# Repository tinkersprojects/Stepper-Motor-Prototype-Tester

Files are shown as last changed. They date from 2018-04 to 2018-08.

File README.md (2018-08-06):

# Stepper-Motor-Prototype-Tester
[https://tinkersprojects.com/](https://tinkersprojects.com/)

This controller is made as a prototype tool to test mechanics from a stepper motor. On the controller, there is a button which is used to change the state of the motor. The controller can have 2 states set, one while the button is pressed ad one while the button is not pressed. The controller can be set using a serial user interface. There are 4 different states that can be set; stop, move to a position, move amount and continuously moving. Stop is stop to stop the motor. Move to a position is to move to a set position. Move amount is to move a set amount no matter what the other set state is. Continuously moving make the motor continuously move at a set speed in a direction.

2 different or the same state can be set, for example; state 1 (button = 0) is continuously moving and state 2 (button = 1) is Move to a position. This will make the motor continuously run but when the button is pressed, the motor will go to the set position. This means that the motor will return to the same spot even tho it has moved away at a random distance.
Another example would be setting the same state but with different speed setting or position settings.
To access the menu, plug the controller into the USB and the menu will appear in the serial console. This menu allows you to set how the controller reacts to the button press.
Welcome v1.0 Stepper motor controller

```
Commads:
    P – Program (ON Type, ON Distance, ON Speed, OFF Type, OFF Distance, OFF Speed)
    A – Move amount (Distance)
    T – Move To positon (Distance)
    S – Set setting (m1, m2, m3)
    D – Display details
    H – Help
Serial.println();
Type:
    0 – Stop
    1 – Move to position
    2 – Move amount
    3 – Continuously moving
```

The Arduino program and PCB is available from https://github.com/tinkersprojects/Stepper-Motor-Prototype-Tester
The PCB is available from https://tinkersprojects.com/product/stepper-motor-prototype-tester/

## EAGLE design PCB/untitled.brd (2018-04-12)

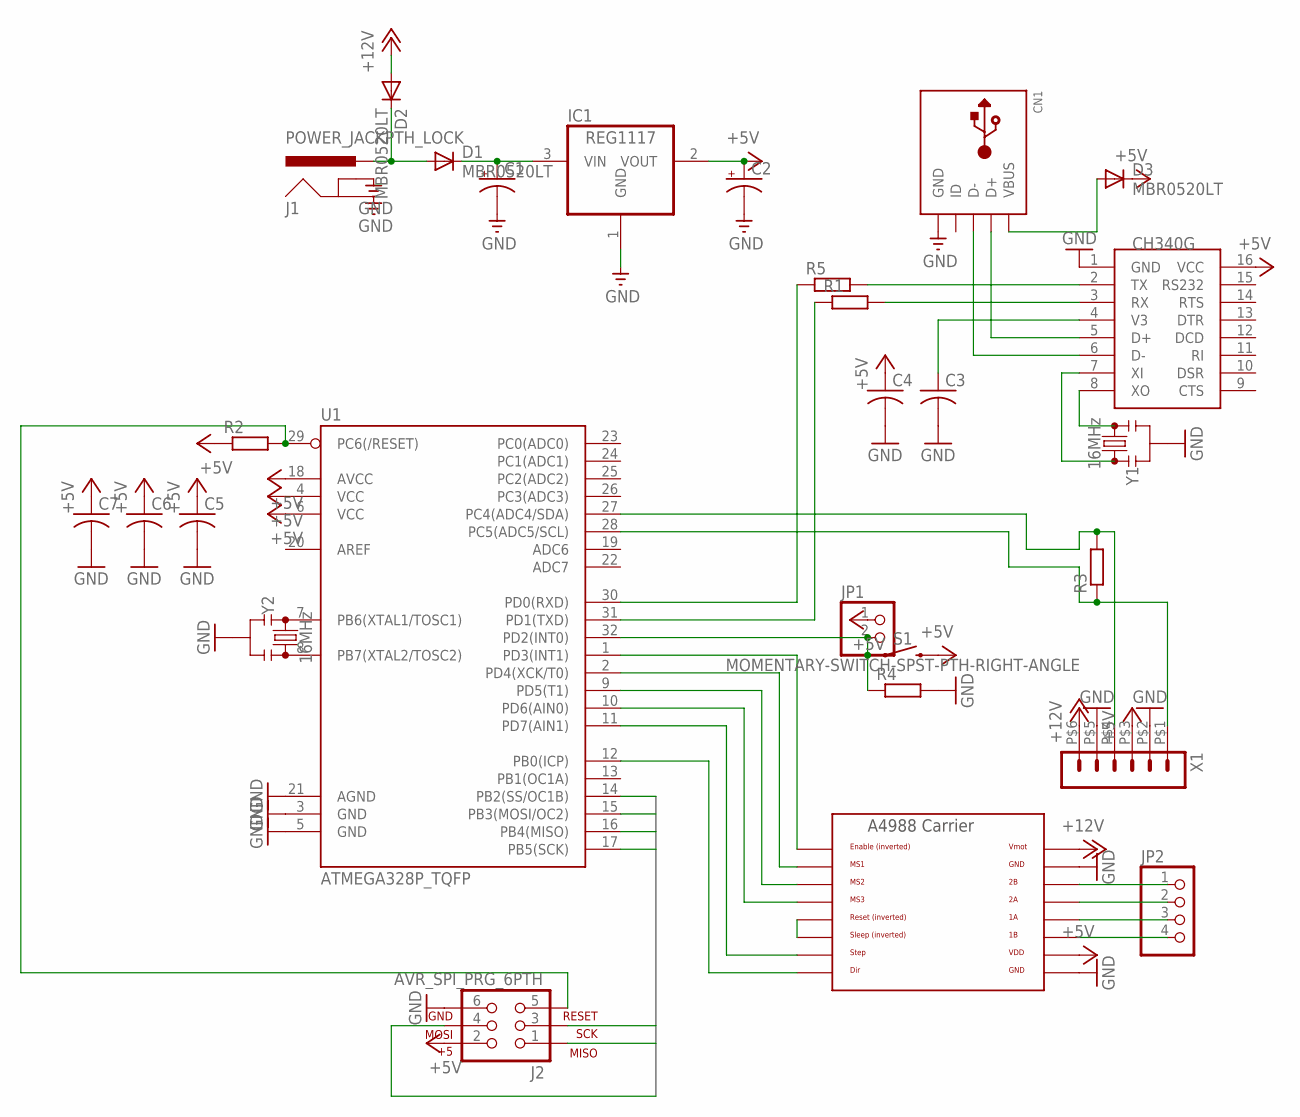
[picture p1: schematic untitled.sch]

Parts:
C1, C2: CPOL-US153CLV-0405; 153CLV-0405
C3, C4, C5, C6, C7: C-USC1210; C1210
CN1: USBMINIB; USB-MINIB
D1, D2, D3: MBR0520LT; SOD123
IC1: REG1117; SOT223
J1: POWER_JACKPTH_LOCK; POWER_JACK_PTH_LOCK
J2: AVR_SPI_PRG_6PTH; 2X3
JP1: PINHD-1X2; 1X02
JP2: PINHD-1X4; 1X04
R1, R2, R3, R4, R5: R-EU_MELF0207W; MINI_MELF-0207W
S1: MOMENTARY-SWITCH-SPST-PTH-RIGHT-ANGLE; TACTILE_SWITCH_PTH_RIGHT_ANGLE
U1: ATMEGA328P_TQFP; TQFP32-08
U$1: CH340G; SOIC16
U$2: A4988BREAKOUT
X1: HEADER_POS6_43045-0600; 43045-0600
Y1, Y2: 16MHz; RESONATOR-SMD-3.2X1.3

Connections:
+5V: C2.+, C4.1, C5.1, C6.1, C7.1, D3.C, IC1.2 (VOUT), J2.2, JP1.1, R2.1, S1.2, U1.4 (VCC), U1.6 (VCC), U1.18 (AVCC), U$1.16 (VCC), U$2.VDD, X1.P$3 (3)
+12V: D2.A, U$2.VMOT, X1.P$6 (6)
CAN_CS: U1.14 (PB2(SS/OC1B))
GND: C1.-, C2.-, C3.2, C4.2, C5.2, C6.2, C7.2, CN1.GND, IC1.1 (GND), J1.GND, J1.GNDBREAK, J2.6, R4.2, U1.3 (GND), U1.5 (GND), U1.21 (AGND), U$1.1 (GND), U$2.GND, U$2.GND@0 (GND), X1.P$2 (2), X1.P$5 (5), Y1.2, Y2.2
MISO: J2.1, U1.16 (PB4(MISO))
MOSI: J2.4, U1.15 (PB3(MOSI/OC2))
unnamed: D1.A, D2.C, J1.PWR
unnamed: R1.2, U$1.3 (RX)
unnamed: U1.1 (PD3(INT1)), U$2.EN
unnamed: U1.2 (PD4(XCK/T0)), U$2.MS1
unnamed: U1.8 (PB7(XTAL2/TOSC2)), Y2.3
unnamed: U1.7 (PB6(XTAL1/TOSC1)), Y2.1
unnamed: J2.5, R2.2, U1.29 (PC6(/RESET))
unnamed: R3.2, U1.27 (PC4(ADC4/SDA)), X1.P$4 (4)
unnamed: U1.9 (PD5(T1)), U$2.MS2
unnamed: U1.10 (PD6(AIN0)), U$2.MS3
unnamed: R3.1, U1.28 (PC5(ADC5/SCL)), X1.P$1 (1)
unnamed: C1.+, D1.C, IC1.3 (VIN)
unnamed: JP1.2, R4.1, S1.1, U1.32 (PD2(INT0))
unnamed: U1.11 (PD7(AIN1)), U$2.STEP
unnamed: U1.12 (PB0(ICP)), U$2.DIR
unnamed: U$2.RST, U$2.SLP (SLEEP)
unnamed: JP2.1, U$2.2B
unnamed: JP2.2, U$2.2A
unnamed: JP2.3, U$2.1A
unnamed: JP2.4, U$2.1B
unnamed: U$1.8 (XO), Y1.3
unnamed: U$1.7 (XI), Y1.1
unnamed: R5.1, U1.30 (PD0(RXD))
unnamed: R1.1, U1.31 (PD1(TXD))
unnamed: R5.2, U$1.2 (TX)
unnamed: CN1.D+, U$1.5 (D+)
unnamed: CN1.D-, U$1.6 (D-)
unnamed: CN1.VBUS, D3.A
unnamed: C3.1, U$1.4 (V3)
SCK: J2.3, U1.17 (PB5(SCK))

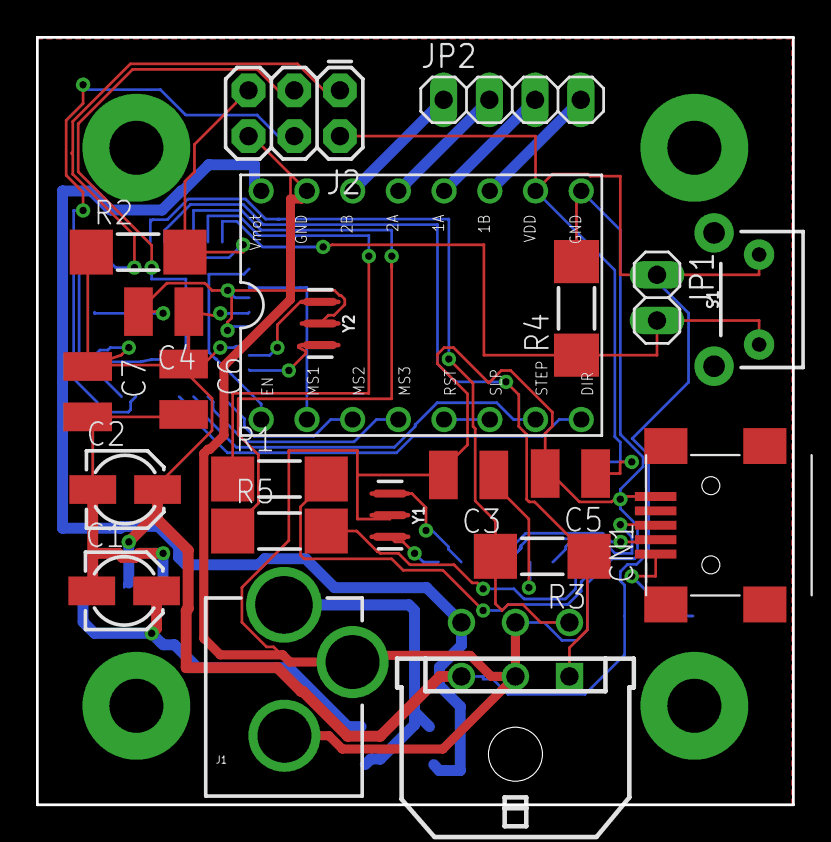
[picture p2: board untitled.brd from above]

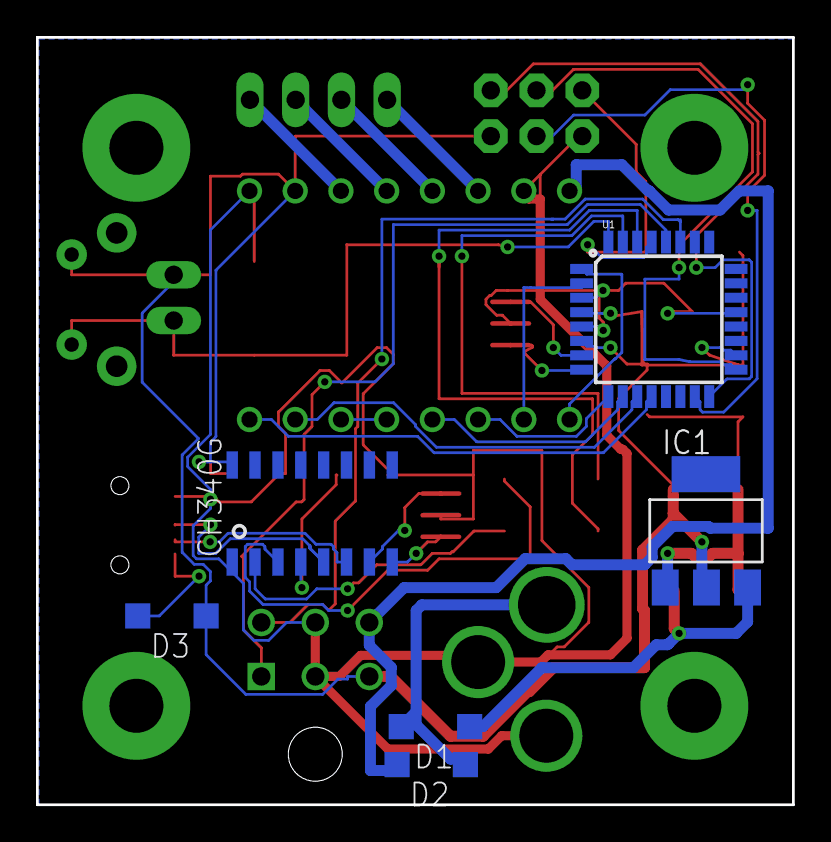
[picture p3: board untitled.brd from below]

Board: 2 copper layers, 42.0 x 42.6 mm, 28 parts (6 on the bottom side), 35 nets.

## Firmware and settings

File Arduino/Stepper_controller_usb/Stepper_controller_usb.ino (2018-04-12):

#include <AccelStepper.h>
#include <EEPROM.h>

//Pins
#define Activepin 2
#define Enablepin 3
#define M1pin 4
#define M2pin 5
#define M3pin 6


boolean last_Activepin_state;

boolean M1 = false;
boolean M2 = false;
boolean M3 = false;

byte   ActiveType = 2;
long ActiveValue = 200;
double ActiveSpeed = 200;

byte   NonActiveType = 2;
long NonActiveValue = 200;
double NonActiveSpeed = 200;



AccelStepper stepper(1,7,8);

void setup() 
{
  read();
  Serial.begin(115200);
  Serial.println("Welcome v1.0 Stepper motor controller");
  Help();
  pinMode(Activepin, OUTPUT);
  pinMode(Enablepin, OUTPUT);
  digitalWrite(Enablepin,LOW);
  setSetting();
  
  stepper.setEnablePin(13);
  stepper.setMaxSpeed(200.0);
  stepper.setAcceleration(100000.0);
  stepper.enableOutputs();

  last_Activepin_state = !digitalRead(Activepin);
}

void loop() 
{
  serialRead();
  runmotor();
}








/****************** MOTOR CONTROL ******************/

void runmotor()
{
  if(last_Activepin_state != digitalRead(Activepin))
  {
    if(digitalRead(Activepin) == HIGH)
    {
      SetMotor(ActiveType, ActiveValue, ActiveSpeed);
    }
    else
    {
      SetMotor(NonActiveType, NonActiveValue, NonActiveSpeed);
    }
    last_Activepin_state = digitalRead(Activepin);
  }
  runsteps();
}

void SetMotor(byte command, long Value, double Speed)
{
  switch(command)
  {
    case 0:  // Stop
      stepper.setSpeed(0);
      stepper.move(0);
    break;
    case 1:  // Move to position
      stepper.setSpeed(Speed);
      stepper.moveTo(Value);
      while(!hasFinshedStepping()){runsteps();}
    break;
    case 2:  // Move Amount from current loction
      stepper.setSpeed(Speed);
      stepper.move(Value);
      while(!hasFinshedStepping()){runsteps();}
    break;
    case 3:  // Move constly 
      stepper.setSpeed(Speed);
      stepper.move(Value);
      last_Activepin_state = digitalRead(Activepin); // needs to be set again
    break;
    case 4:  // Move to position and can be interupeted
      stepper.setSpeed(Speed);
      stepper.moveTo(Value);
    break;
    case 5:  // Move Amount from current loction and can be interupeted
      stepper.setSpeed(Speed);
      stepper.move(Value);
    break;
  }
}

void setSetting()
{
  if(M1)
  digitalWrite(M1pin,HIGH);
  else
  digitalWrite(M1pin,LOW);
  
  if(M2)
  digitalWrite(M2pin,HIGH);
  else
  digitalWrite(M2pin,LOW);
  
  if(M3)
  digitalWrite(M3pin,HIGH);
  else
  digitalWrite(M3pin,LOW);
}

bool hasFinshedStepping()
{
    return stepper.distanceToGo()!=0;
}

void runsteps()
{
  stepper.run();
}







/****************** COMPUTER INTERFACE ******************/

String inputString = "";
char menu = 0;
char menuStep = 0;

void serialRead() 
{
  while (Serial.available()) 
  {
    char inChar = (char)Serial.read();
    if(menu == 0)
    {
      if(inChar>='a')inChar = inChar - ('a'-'A');
      menu = inChar;
      menuStep = 0;
      while((char)Serial.read() != '\n'){runmotor();}
      ReceiveCommand(0);
      inputString = "";
      return;
    }
    else
    {
      if (inChar == '\n') 
      {
        menuStep++;
        ReceiveCommand(inputString.toDouble());
        inputString = "";
        return;
      }
      else
      {
        inputString += inChar;
      }
    }
  }
}

void ReceiveCommand(double Value)
{
   switch(menu)
   {
     case 'H': 
      Help();
      break;
     case 'P':
      Program(Value); 
      break;
     case 'A': 
      MoveAmount(Value);
      break;
     case 'T': 
      MoveTo(Value);
      break;
     case 'S': 
      Setting(Value);
      break;
     case 'D': 
      Display();
      break;
   }
}


void Program(double Value)
{
  if((menuStep == 2 && Value == 3) || (menuStep == 5 && Value == 3)) menuStep++;

  switch(menuStep)
  {
    case 1:
      Serial.print("Enter ON Type:");
    break;
    case 2:
      ActiveType = Value;
      Serial.println(Value);
      Serial.print("Enter ON Distance:");
    break;
    case 3:
      ActiveValue = Value;
      Serial.println(Value);
      Serial.print("Enter ON Speed:");
    break;
    case 4:
      ActiveSpeed = Value;
      Serial.println(Value);
      Serial.print("Enter OFF Type:");
    break;
    case 5:
      NonActiveType = Value;
      Serial.println(Value);
      Serial.print("Enter OFF Distance:");
    break;
    case 6:
      NonActiveValue = Value;
      Serial.println(Value);
      Serial.print("Enter OFF Speed:");
    break;
    case 7:
      NonActiveSpeed = Value;
      menu = 0;
      Serial.println(Value);
      Serial.println("Save");
      save();
    break;
  }
}

void MoveAmount(double Value)
{
  stepper.move(Value);
  menu = 0;
}

void MoveTo(double Value)
{
  stepper.moveTo(Value);
  menu = 0;
}

void Setting(double Value)
{
  switch(menuStep)
  {
    case 1:
      Serial.print("Enter M1:");
    break;
    case 2:
      if(Value >0)
        M1 = true;
      else
        M1 = false;
      Serial.println(M1);
      Serial.print("Enter M2:");
    break;
    case 3:
      if(Value >0)
        M2 = true;
      else
        M2 = false;
      Serial.println(M2);
      Serial.print("Enter M3:");
    break;
    case 4:
      if(Value >0)
        M3 = true;
      else
        M3 = false;
      menu = 0;
      Serial.println(M3);
      Serial.println("Save");
      save();
      setSetting();
    break;
  }
}


void Help()
{
  menu = 0;
  Serial.println("Commads:");
  Serial.println("\tP - Program (ON Type, ON Distance, ON Speed, OFF Type, OFF Distance, OFF Speed)");
  Serial.println("\tA - Move amount (Distance)");
  Serial.println("\tT - Move To positon (Distance)");
  Serial.println("\tS - Set setting (m1, m2, m3)");
  Serial.println("\tD - Display details");
  Serial.println("\tH - Help");
  Serial.println();
  Serial.println("Type:");
  Serial.println("\t0 - Stop");
  Serial.println("\t1 - Move to position");
  Serial.println("\t2 - Move amount");
  Serial.println("\t3 - Continuously moving");
}



void Display()
{
  menu = 0;
  Serial.println("ON:");
  Serial.print("\tType: ");
  Serial.println(ActiveType);
  Serial.print("\tDistance: ");
  Serial.println(ActiveValue);
  Serial.print("\tSpeed:");
  Serial.println(ActiveSpeed);
  Serial.println();
  Serial.println("OFF:");
  Serial.print("\tType: ");
  Serial.println(NonActiveType);
  Serial.print("\tDistance: ");
  Serial.println(NonActiveValue);
  Serial.print("\tSpeed: ");
  Serial.println(NonActiveSpeed);
  Serial.println();
  Serial.println("Settings:");
  Serial.print("\tM1: ");
  Serial.println(M1);
  Serial.print("\tM2: ");
  Serial.println(M2);
  Serial.print("\tM3: ");
  Serial.println(M3);
  Serial.println();
}







/****************** STORAGE ******************/

void read()
{
  if(EEPROM.read(0) == 1)
  {
    M1 = EEPROM.read(1);
    M2 = EEPROM.read(2);
    M3 = EEPROM.read(3);

    String readString = "";
    char letter = 0;
    for(int i = 20;i<2000;i++)
    {
      char CHAR = EEPROM.read(i);
      if(CHAR >= 'A' && CHAR < 'Z' && letter != 0)
      {
        switch(letter)
        {
          case 'A':
            ActiveType = readString.toInt();
          break;
          case 'B':
            ActiveValue = readString.toInt();
          break;
          case 'C':
            ActiveSpeed = readString.toDouble();
          break;
          case 'D':
            NonActiveType = readString.toInt();
          break;
          case 'E':
            NonActiveValue = readString.toInt();
          break;
          case 'F':
            NonActiveSpeed = readString.toDouble();
          break;
          case 'G':
            return;
          break;
        }
      }
      if(CHAR >= 'A' && CHAR < 'Z')
      {
        letter = CHAR;
        readString = "";
      }
      else
      {
        readString += CHAR;
      }
    }
  }
  else
  {
    save();
  }
}

void save()
{
  EEPROM.write(0, 1);
  EEPROM.write(1, M1);
  EEPROM.write(2, M2);
  EEPROM.write(3, M3);

  String saveString = "A"+String(ActiveType);
  saveString += "B"+String(ActiveValue);
  saveString += "C"+String(ActiveSpeed);
  saveString += "D"+String(NonActiveType);
  saveString += "E"+String(NonActiveValue);
  saveString += "F"+String(NonActiveSpeed);
  saveString += "G";

  for(int i = 0;i<saveString.length();i++)
  {
    EEPROM.write(20+i, saveString.charAt(i));
  }
}

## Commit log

2018-04-12 Add files via upload
    upload Arduino files
2018-04-12 Add files via upload
    upload PCB files
    [untitled.brd, untitled.sch]

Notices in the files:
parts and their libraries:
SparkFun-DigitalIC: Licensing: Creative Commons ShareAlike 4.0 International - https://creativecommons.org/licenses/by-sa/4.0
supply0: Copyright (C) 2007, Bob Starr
